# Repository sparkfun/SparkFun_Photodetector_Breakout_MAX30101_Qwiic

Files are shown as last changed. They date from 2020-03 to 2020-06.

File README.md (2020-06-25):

SparkFun Photodetector Breakout - MAX30101 (Qwiic)
========================================

SparkFun Photodetector Breakout - MAX30101) (https://www.sparkfun.com/products/16474)

[*SparkFun Photodetector Breakout - MAX30101 (Qwiic) (SEN-16474)*](https://www.sparkfun.com/products/16474)

This updated version of the [SparkFun Particle Sensor Breakout](https://www.sparkfun.com/products/14045) includes the MAX30101, a highly sensitive optical sensor and successor to the MAX30105 and MAX30102. The MAX30101 includes three LEDs and an optical detector in a single package. The operating principle behind the sensor, utilizes the photon detector to measure the amount of light that is reflected back from the light being emitted by the LEDs. This is useful for various applications like particle (*i.e. smoke*) detection, proximity measurements, and even [photoplethysmography](https://en.wikipedia.org/wiki/Photoplethysmogram). For more accurate and reliable biometric readings, we recommend the [SparkFun Pulse Oximeter and Heart Rate Sensor](https://www.sparkfun.com/products/15219), which utilizes proprietary algorithms programmed on the MAX32664 Biometric Sensor Hub.

<div class="alert alert-danger"><a href="https://www.sparkfun.com/terms"><b>&#9760; NOTE:</b> Our products are <b><u>NOT</u></b> intended to diagnose or treat any conditions and in life saving applications.</a></div>

Repository Contents
-------------------

* **/Documentation** - Data sheets, additional product information
* **/Hardware** - Eagle design files (.brd, .sch)
* **/Hardware/Production** - Production panel files and gerbers (.brd)

Documentation
--------------

* **[Hookup Guide](https://learn.sparkfun.com/tutorials/sparkfun-photodetector-max30101-hookup-guide)** - Basic hookup guide for the SparkFun Photodetector Breakout - MAX30101 (Qwiic).
* **[Python Package](https://github.com/sparkfun/Qwiic_MAX3010x_Py)** - Python package with examples. Pip and Pip3 install supported!!
* **[Arduino Library](https://github.com/sparkfun/SparkFun_MAX3010x_Sensor_Library)** - Basic Arduino Library for the SparkFun Photodetector Breakout - MAX30101 (Qwiic).

License Information
-------------------

This product is _**open source**_! 

Please review the LICENSE.md file for license information. 

If you have any questions or concerns on licensing, please contact technical support on our [SparkFun forums](https://forum.sparkfun.com/viewforum.php?f=152).

Distributed as-is; no warranty is given.

- Your friends at SparkFun.

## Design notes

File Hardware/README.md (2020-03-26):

SparkFun Particle Sensor MAX30101 (Qwiic) Design Files
=====================================

The .sch and .brd files hare are Eagle CAD schematic and PCB design files from SparkFun Electronics.
A freeware version of Eagle can be found [here](https://www.autodesk.com/products/eagle/free-download).

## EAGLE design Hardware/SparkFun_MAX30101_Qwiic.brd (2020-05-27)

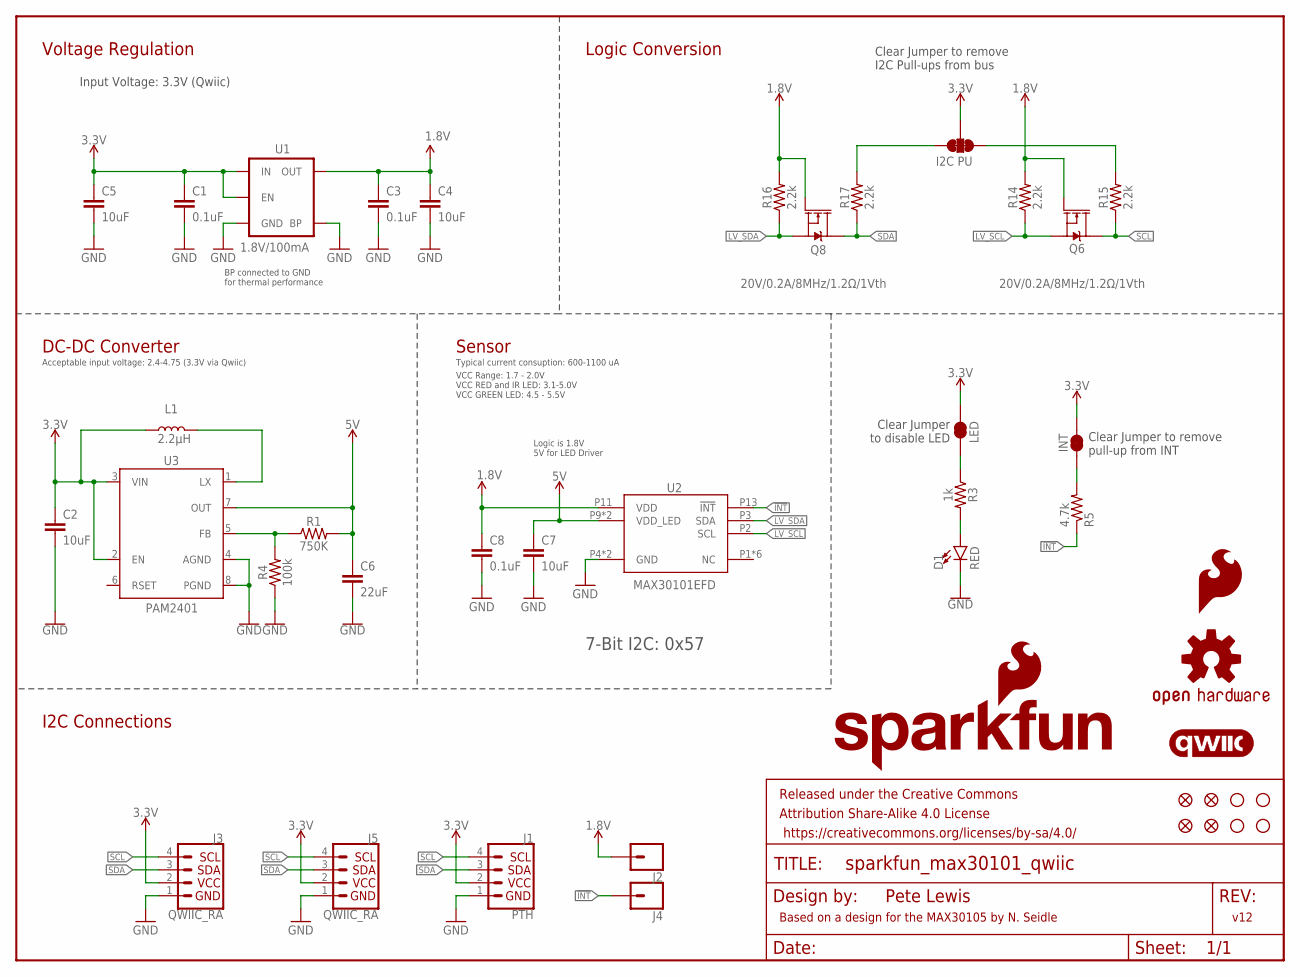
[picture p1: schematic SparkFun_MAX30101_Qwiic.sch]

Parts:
C1, C3, C8: 0.1uF; 0402
C2, C4, C5, C7: 10uF; 0603
C6: 22uF; 0805
D1: RED; LED-0603
FID1, FID2, FID3, FID4: FIDUCIAL1X2; FIDUCIAL-1X2
FRAME1: FRAME-LETTER; CREATIVE_COMMONS
J1: PTH; 1X04_NO_SILK
J2, J4: CONN_01PTH_NO_SILK_YES_STOP; 1X01_NO_SILK
J3, J5: QWIIC_RA; JST04_1MM_RA
JP1: LED; SMT-JUMPER_2_NC_TRACE_SILK
JP2: INT; SMT-JUMPER_2_NC_TRACE_SILK
JP4: I2C PU; SMT-JUMPER_3_2-NC_TRACE_SILK
L1: 2.2μH; 0806
LOGO1: SFE_LOGO_NAME_FLAME.1_INCH; SFE_LOGO_NAME_FLAME_.1
LOGO2: OSHW-LOGOS; OSHW-LOGO-S
LOGO3: QWIIC_LOGO_5MM; QWIIC_5MM
LOGO4: SFE_LOGO_FLAME.1_INCH; SFE_LOGO_FLAME_.1
Q6, Q8: 20V/0.2A/8MHz/1.2Ω/1Vth; SOT-416FL
R1: 750K; 0603
R3: 1k; 0603
R4: 100k; 0603
R5: 4.7k; 0603
R14, R15, R16, R17: 2.2k; 0603
STANDOFF1, STANDOFF2, STANDOFF3, STANDOFF4: STAND-OFF
U1: 1.8V/100mA; SC70
U2: MAX30101EFD; 14_PIN_OESIP
U3: PAM2401; MSOP8

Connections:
1.8V: C3.1, C4.1, C8.1, J2.1, Q6.1 (G), Q8.1 (G), R14.2, R16.2, U1.5 (OUT), U2.P11 (VDD)
3.3V: C1.1, C2.1, C5.1, J1.2, J3.2, J5.2, JP1.2, JP2.2, JP4.2, L1.1, U1.1 (IN), U1.3 (EN), U3.2 (EN), U3.3 (VIN)
5V: C6.1, C7.1, R1.2, U2.P9 (VDD_LED), U2.P10 (VDD_LED), U3.7 (OUT)
!INT: J4.1, R5.1, U2.P13 (!INT)
GND: C1.2, C2.2, C3.2, C4.2, C5.2, C6.2, C7.2, C8.2, D1.C, J1.1, J3.1, J5.1, R4.1, U1.2 (GND), U1.4 (BP), U2.P4 (GND), U2.P12 (GND), U3.4 (AGND), U3.8 (PGND)
LV_SCL: Q6.2 (S), R14.1, U2.P2 (SCL)
LV_SDA: Q8.2 (S), R16.1, U2.P3 (SDA)
unnamed: JP2.1, R5.2
unnamed: R1.1, R4.2, U3.5 (FB)
unnamed: L1.2, U3.1 (LX)
unnamed: D1.A, R3.2
unnamed: JP4.3, R15.2
unnamed: JP4.1, R17.2
unnamed: JP1.1, R3.1
SCL: J1.4, J3.4, J5.4, Q6.3 (D), R15.1
SDA: J1.3, J3.3, J5.3, Q8.3 (D), R17.1

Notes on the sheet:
7-Bit I2C: 0x57
v12
Pete Lewis
Voltage Regulation
Logic Conversion
Sensor
Input Voltage: 3.3V (Qwiic)
Clear Jumper to remove I2C Pull-ups from bus
Clear Jumper to remove pull-up from INT
Logic is 1.8V 5V for LED Driver
BP connected to GND for thermal performance
I2C Connections
Based on a design for the MAX30105 by N. Seidle
Clear Jumper to disable LED
DC-DC Converter
Typical current consuption: 600-1100 uA
VCC Range: 1.7 - 2.0V VCC RED and IR LED: 3.1-5.0V VCC GREEN LED: 4.5 - 5.5V
Acceptable input voltage: 2.4-4.75 (3.3V via Qwiic)

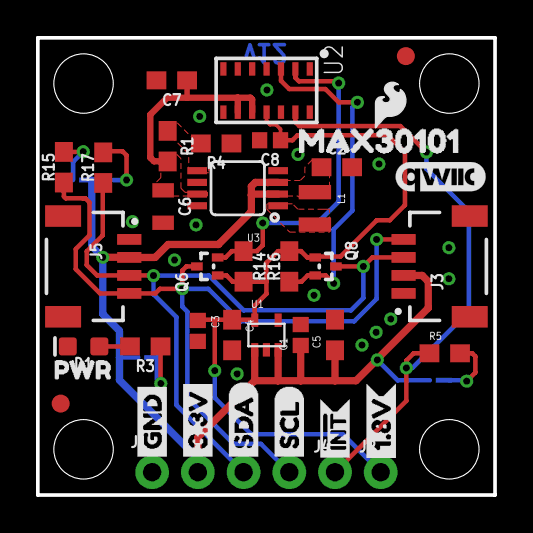
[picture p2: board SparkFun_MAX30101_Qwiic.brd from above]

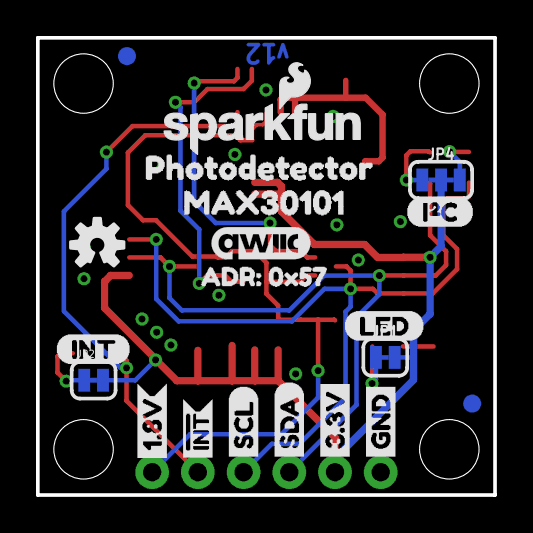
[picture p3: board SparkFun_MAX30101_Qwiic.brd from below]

Board: 2 copper layers, 25.4 x 25.4 mm, 65 parts (20 on the bottom side), 16 nets.

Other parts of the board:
U$1: PHOTODETECTOR3
U$3, U$11: INT#-[<-04
U$4, U$24: MAX301010
U$7: INT-()-04
U$8: LED0
U$9, U$12: SCL-[)
U$10, U$23: GND-04
U$13, U$14: SDA-[)
U$15: ADR#_0X570
U$16: QWIIC_5.5MM
U$19, U$22: 3.3V
U$20, U$27: 1#8V0
U$21: I_SUPER2_C-()-04
U$26: PWR_TO

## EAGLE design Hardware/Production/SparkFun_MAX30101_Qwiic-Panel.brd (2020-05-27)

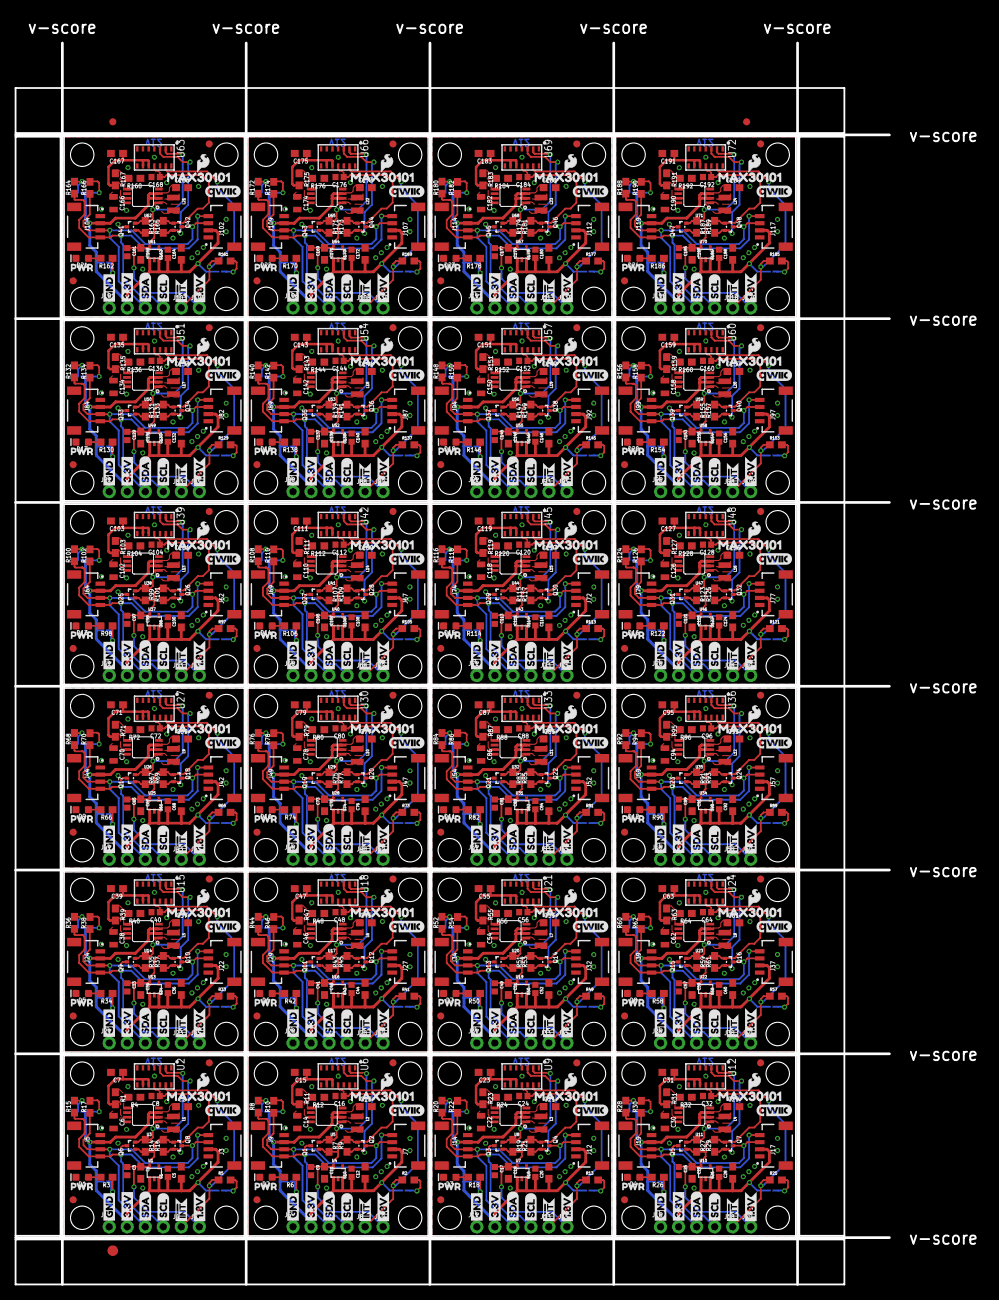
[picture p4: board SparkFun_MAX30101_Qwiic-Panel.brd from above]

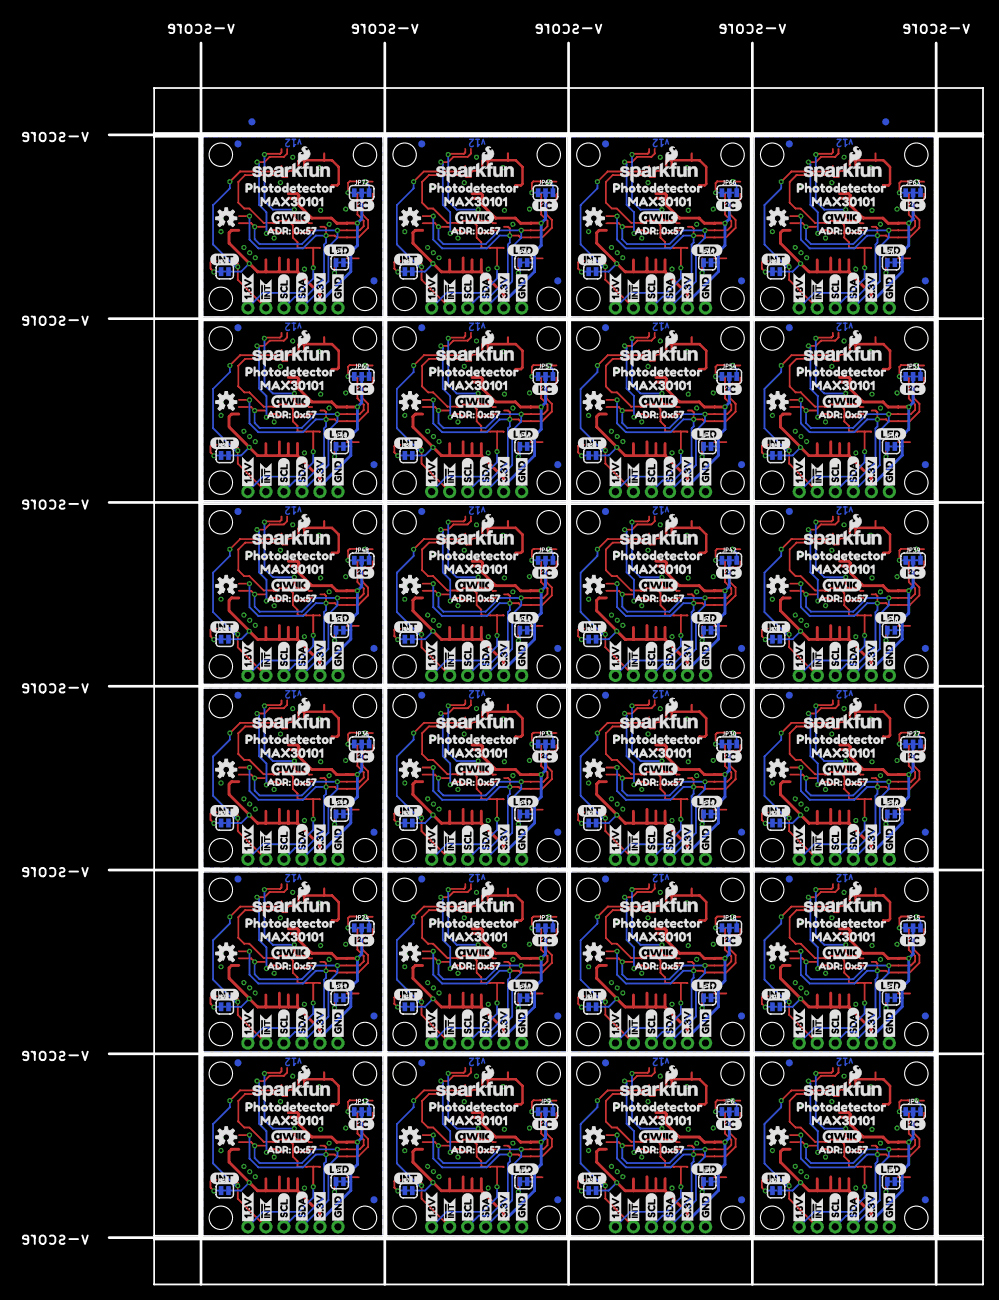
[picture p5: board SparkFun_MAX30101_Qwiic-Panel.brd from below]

Board: 2 copper layers, 123.2 x 175.0 mm, 1541 parts (482 on the bottom side), 384 nets.

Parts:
C1, C3, C8, C9, C10, C16, C17, C18, C24, C25, C26, C32, C33, C34, C40, C41, C42, C48, C49, C50, C56, C57, C58, C64, C65, C66, C72, C73, C74, C80, C81, C82, C88, C89, C90, C96, C97, C98, C104, C105, C106, C112, C113, C114, C120, C121, C122, C128, C129, C130, C136, C137, C138, C144, C145, C146, C152, C153, C154, C160, C161, C162, C168, C169, C170, C176, C177, C178, C184, C185, C186, C192: 0.1uF; 0402
C2, C4, C5, C7, C11, C12, C13, C15, C19, C20, C21, C23, C27, C28, C29, C31, C35, C36, C37, C39, C43, C44, C45, C47, C51, C52, C53, C55, C59, C60, C61, C63, C67, C68, C69, C71, C75, C76, C77, C79, C83, C84, C85, C87, C91, C92, C93, C95, C99, C100, C101, C103, C107, C108, C109, C111, C115, C116, C117, C119, C123, C124, C125, C127, C131, C132, C133, C135, C139, C140, C141, C143, C147, C148, C149, C151, C155, C156, C157, C159, C163, C164, C165, C167, C171, C172, C173, C175, C179, C180, C181, C183, C187, C188, C189, C191: 10uF; 0603
C6, C14, C22, C30, C38, C46, C54, C62, C70, C78, C86, C94, C102, C110, C118, C126, C134, C142, C150, C158, C166, C174, C182, C190: 22uF; 0805
D1, D2, D3, D4, D5, D6, D7, D8, D9, D10, D11, D12, D13, D14, D15, D16, D17, D18, D19, D20, D21, D22, D23, D24: RED; LED-0603
E$1, E$2, E$3, E$4: FIDUCIAL-1X2
E$5: FIDUCIAL-1.5X3
FID1, FID2, FID3, FID4, FID5, FID6, FID7, FID8, FID9, FID10, FID11, FID12, FID13, FID14, FID15, FID16, FID17, FID18, FID19, FID20, FID21, FID22, FID23, FID24, FID25, FID26, FID27, FID28, FID29, FID30, FID31, FID32, FID33, FID34, FID35, FID36, FID37, FID38, FID39, FID40, FID41, FID42, FID43, FID44, FID45, FID46, FID47, FID48, FID49, FID50, FID51, FID52, FID53, FID54, FID55, FID56, FID57, FID58, FID59, FID60, FID61, FID62, FID63, FID64, FID65, FID66, FID67, FID68, FID69, FID70, FID71, FID72, FID73, FID74, FID75, FID76, FID77, FID78, FID79, FID80, FID81, FID82, FID83, FID84, FID85, FID86, FID87, FID88, FID89, FID90, FID91, FID92, FID93, FID94, FID95, FID96: FIDUCIAL1X2; FIDUCIAL-1X2
J1, J6, J11, J16, J21, J26, J31, J36, J41, J46, J51, J56, J61, J66, J71, J76, J81, J86, J91, J96, J101, J106, J111, J116: PTH; 1X04_NO_SILK
J2, J4, J8, J10, J13, J15, J18, J20, J23, J25, J28, J30, J33, J35, J38, J40, J43, J45, J48, J50, J53, J55, J58, J60, J63, J65, J68, J70, J73, J75, J78, J80, J83, J85, J88, J90, J93, J95, J98, J100, J103, J105, J108, J110, J113, J115, J118, J120: 1X01_NO_SILK
J3, J5, J7, J9, J12, J14, J17, J19, J22, J24, J27, J29, J32, J34, J37, J39, J42, J44, J47, J49, J52, J54, J57, J59, J62, J64, J67, J69, J72, J74, J77, J79, J82, J84, J87, J89, J92, J94, J97, J99, J102, J104, J107, J109, J112, J114, J117, J119: QWIIC_RA; JST04_1MM_RA
JP1, JP5, JP8, JP11, JP14, JP17, JP20, JP23, JP26, JP29, JP32, JP35, JP38, JP41, JP44, JP47, JP50, JP53, JP56, JP59, JP62, JP65, JP68, JP71: LED; SMT-JUMPER_2_NC_TRACE_SILK
JP2, JP3, JP7, JP10, JP13, JP16, JP19, JP22, JP25, JP28, JP31, JP34, JP37, JP40, JP43, JP46, JP49, JP52, JP55, JP58, JP61, JP64, JP67, JP70: INT; SMT-JUMPER_2_NC_TRACE_SILK
JP4, JP6, JP9, JP12, JP15, JP18, JP21, JP24, JP27, JP30, JP33, JP36, JP39, JP42, JP45, JP48, JP51, JP54, JP57, JP60, JP63, JP66, JP69, JP72: I2C PU; SMT-JUMPER_3_2-NC_TRACE_SILK
L1, L2, L3, L4, L5, L6, L7, L8, L9, L10, L11, L12, L13, L14, L15, L16, L17, L18, L19, L20, L21, L22, L23, L24: 2.2μH; 0806
LOGO1, LOGO5, LOGO9, LOGO13, LOGO17, LOGO21, LOGO25, LOGO29, LOGO33, LOGO37, LOGO41, LOGO45, LOGO49, LOGO53, LOGO57, LOGO61, LOGO65, LOGO69, LOGO73, LOGO77, LOGO81, LOGO85, LOGO89, LOGO93: SFE_LOGO_NAME_FLAME.1_INCH; SFE_LOGO_NAME_FLAME_.1
LOGO2, LOGO6, LOGO10, LOGO14, LOGO18, LOGO22, LOGO26, LOGO30, LOGO34, LOGO38, LOGO42, LOGO46, LOGO50, LOGO54, LOGO58, LOGO62, LOGO66, LOGO70, LOGO74, LOGO78, LOGO82, LOGO86, LOGO90, LOGO94: OSHW-LOGOS; OSHW-LOGO-S
LOGO3, LOGO8, LOGO12, LOGO16, LOGO20, LOGO24, LOGO28, LOGO32, LOGO36, LOGO40, LOGO44, LOGO48, LOGO52, LOGO56, LOGO60, LOGO64, LOGO68, LOGO72, LOGO76, LOGO80, LOGO84, LOGO88, LOGO92, LOGO96: QWIIC_LOGO_5MM; QWIIC_5MM
LOGO4, LOGO7, LOGO11, LOGO15, LOGO19, LOGO23, LOGO27, LOGO31, LOGO35, LOGO39, LOGO43, LOGO47, LOGO51, LOGO55, LOGO59, LOGO63, LOGO67, LOGO71, LOGO75, LOGO79, LOGO83, LOGO87, LOGO91, LOGO95: SFE_LOGO_FLAME.1_INCH; SFE_LOGO_FLAME_.1
Q1, Q2, Q3, Q4, Q5, Q6, Q7, Q8, Q9, Q10, Q11, Q12, Q13, Q14, Q15, Q16, Q17, Q18, Q19, Q20, Q21, Q22, Q23, Q24, Q25, Q26, Q27, Q28, Q29, Q30, Q31, Q32, Q33, Q34, Q35, Q36, Q37, Q38, Q39, Q40, Q41, Q42, Q43, Q44, Q45, Q46, Q47, Q48: 20V/0.2A/8MHz/1.2Ω/1Vth; SOT-416FL
R1, R11, R23, R31, R39, R47, R55, R63, R71, R79, R87, R95, R103, R111, R119, R127, R135, R143, R151, R159, R167, R175, R183, R191: 750K; 0603
R2, R5, R13, R25, R33, R41, R49, R57, R65, R73, R81, R89, R97, R105, R113, R121, R129, R137, R145, R153, R161, R169, R177, R185: 4.7k; 0603
R3, R6, R18, R26, R34, R42, R50, R58, R66, R74, R82, R90, R98, R106, R114, R122, R130, R138, R146, R154, R162, R170, R178, R186: 1k; 0603
R4, R12, R24, R32, R40, R48, R56, R64, R72, R80, R88, R96, R104, R112, R120, R128, R136, R144, R152, R160, R168, R176, R184, R192: 100k; 0603
R7, R8, R9, R10, R14, R15, R16, R17, R19, R20, R21, R22, R27, R28, R29, R30, R35, R36, R37, R38, R43, R44, R45, R46, R51, R52, R53, R54, R59, R60, R61, R62, R67, R68, R69, R70, R75, R76, R77, R78, R83, R84, R85, R86, R91, R92, R93, R94, R99, R100, R101, R102, R107, R108, R109, R110, R115, R116, R117, R118, R123, R124, R125, R126, R131, R132, R133, R134, R139, R140, R141, R142, R147, R148, R149, R150, R155, R156, R157, R158, R163, R164, R165, R166, R171, R172, R173, R174, R179, R180, R181, R182, R187, R188, R189, R190: 2.2k; 0603
STANDOFF1, STANDOFF2, STANDOFF3, STANDOFF4, STANDOFF5, STANDOFF6, STANDOFF7, STANDOFF8, STANDOFF9, STANDOFF10, STANDOFF11, STANDOFF12, STANDOFF13, STANDOFF14, STANDOFF15, STANDOFF16, STANDOFF17, STANDOFF18, STANDOFF19, STANDOFF20, STANDOFF21, STANDOFF22, STANDOFF23, STANDOFF24, STANDOFF25, STANDOFF26, STANDOFF27, STANDOFF28, STANDOFF29, STANDOFF30, STANDOFF31, STANDOFF32, STANDOFF33, STANDOFF34, STANDOFF35, STANDOFF36, STANDOFF37, STANDOFF38, STANDOFF39, STANDOFF40, STANDOFF41, STANDOFF42, STANDOFF43, STANDOFF44, STANDOFF45, STANDOFF46, STANDOFF47, STANDOFF48, STANDOFF49, STANDOFF50, STANDOFF51, STANDOFF52, STANDOFF53, STANDOFF54, STANDOFF55, STANDOFF56, STANDOFF57, STANDOFF58, STANDOFF59, STANDOFF60, STANDOFF61, STANDOFF62, STANDOFF63, STANDOFF64, STANDOFF65, STANDOFF66, STANDOFF67, STANDOFF68, STANDOFF69, STANDOFF70, STANDOFF71, STANDOFF72, STANDOFF73, STANDOFF74, STANDOFF75, STANDOFF76, STANDOFF77, STANDOFF78, STANDOFF79, STANDOFF80, STANDOFF81, STANDOFF82, STANDOFF83, STANDOFF84, STANDOFF85, STANDOFF86, STANDOFF87, STANDOFF88, STANDOFF89, STANDOFF90, STANDOFF91, STANDOFF92, STANDOFF93, STANDOFF94, STANDOFF95, STANDOFF96: STAND-OFF
U1, U4, U7, U10, U13, U16, U19, U22, U25, U28, U31, U34, U37, U40, U43, U46, U49, U52, U55, U58, U61, U64, U67, U70: 1.8V/100mA; SC70
U2, U6, U9, U12, U15, U18, U21, U24, U27, U30, U33, U36, U39, U42, U45, U48, U51, U54, U57, U60, U63, U66, U69, U72: MAX30101EFD; 14_PIN_OESIP
U3, U5, U8, U11, U14, U17, U20, U23, U26, U29, U32, U35, U38, U41, U44, U47, U50, U53, U56, U59, U62, U65, U68, U71: PAM2401; MSOP8
U$1, U$42, U$63, U$84, U$105, U$126, U$147, U$168, U$189, U$210, U$231, U$252, U$273, U$294, U$315, U$336, U$357, U$378, U$399, U$420, U$441, U$462, U$483, U$504: PHOTODETECTOR3
U$2, U$3, U$6, U$11, U$43, U$45, U$64, U$66, U$85, U$87, U$106, U$108, U$127, U$129, U$148, U$150, U$169, U$171, U$190, U$192, U$211, U$213, U$232, U$234, U$253, U$255, U$274, U$276, U$295, U$297, U$316, U$318, U$337, U$339, U$358, U$360, U$379, U$381, U$400, U$402, U$421, U$423, U$442, U$444, U$463, U$465, U$484, U$486: INT#-[<-04
U$4, U$24, U$35, U$37, U$56, U$58, U$77, U$79, U$98, U$100, U$119, U$121, U$140, U$142, U$161, U$163, U$182, U$184, U$203, U$205, U$224, U$226, U$245, U$247, U$266, U$268, U$287, U$289, U$308, U$310, U$329, U$331, U$350, U$352, U$371, U$373, U$392, U$394, U$413, U$415, U$434, U$436, U$455, U$457, U$476, U$478, U$497, U$499: MAX301010
U$5, U$9, U$12, U$29, U$44, U$50, U$65, U$71, U$86, U$92, U$107, U$113, U$128, U$134, U$149, U$155, U$170, U$176, U$191, U$197, U$212, U$218, U$233, U$239, U$254, U$260, U$275, U$281, U$296, U$302, U$317, U$323, U$338, U$344, U$359, U$365, U$380, U$386, U$401, U$407, U$422, U$428, U$443, U$449, U$464, U$470, U$485, U$491: SCL-[)
U$7, U$32, U$53, U$74, U$95, U$116, U$137, U$158, U$179, U$200, U$221, U$242, U$263, U$284, U$305, U$326, U$347, U$368, U$389, U$410, U$431, U$452, U$473, U$494: INT-()-04
U$8, U$34, U$55, U$76, U$97, U$118, U$139, U$160, U$181, U$202, U$223, U$244, U$265, U$286, U$307, U$328, U$349, U$370, U$391, U$412, U$433, U$454, U$475, U$496: LED0
U$10, U$23, U$25, U$28, U$48, U$49, U$69, U$70, U$90, U$91, U$111, U$112, U$132, U$133, U$153, U$154, U$174, U$175, U$195, U$196, U$216, U$217, U$237, U$238, U$258, U$259, U$279, U$280, U$300, U$301, U$321, U$322, U$342, U$343, U$363, U$364, U$384, U$385, U$405, U$406, U$426, U$427, U$447, U$448, U$468, U$469, U$489, U$490: GND-04
U$13, U$14, U$30, U$31, U$51, U$52, U$72, U$73, U$93, U$94, U$114, U$115, U$135, U$136, U$156, U$157, U$177, U$178, U$198, U$199, U$219, U$220, U$240, U$241, U$261, U$262, U$282, U$283, U$303, U$304, U$324, U$325, U$345, U$346, U$366, U$367, U$387, U$388, U$408, U$409, U$429, U$430, U$450, U$451, U$471, U$472, U$492, U$493: SDA-[)
U$15, U$38, U$59, U$80, U$101, U$122, U$143, U$164, U$185, U$206, U$227, U$248, U$269, U$290, U$311, U$332, U$353, U$374, U$395, U$416, U$437, U$458, U$479, U$500: ADR#_0X570
U$16, U$36, U$57, U$78, U$99, U$120, U$141, U$162, U$183, U$204, U$225, U$246, U$267, U$288, U$309, U$330, U$351, U$372, U$393, U$414, U$435, U$456, U$477, U$498: QWIIC_5.5MM
U$17, U$18, U$19, U$22, U$46, U$47, U$67, U$68, U$88, U$89, U$109, U$110, U$130, U$131, U$151, U$152, U$172, U$173, U$193, U$194, U$214, U$215, U$235, U$236, U$256, U$257, U$277, U$278, U$298, U$299, U$319, U$320, U$340, U$341, U$361, U$362, U$382, U$383, U$403, U$404, U$424, U$425, U$445, U$446, U$466, U$467, U$487, U$488: 3.3V
U$20, U$27, U$40, U$41, U$61, U$62, U$82, U$83, U$103, U$104, U$124, U$125, U$145, U$146, U$166, U$167, U$187, U$188, U$208, U$209, U$229, U$230, U$250, U$251, U$271, U$272, U$292, U$293, U$313, U$314, U$334, U$335, U$355, U$356, U$376, U$377, U$397, U$398, U$418, U$419, U$439, U$440, U$460, U$461, U$481, U$482, U$502, U$503: 1#8V0
U$21, U$33, U$54, U$75, U$96, U$117, U$138, U$159, U$180, U$201, U$222, U$243, U$264, U$285, U$306, U$327, U$348, U$369, U$390, U$411, U$432, U$453, U$474, U$495: I_SUPER2_C-()-04
U$26, U$39, U$60, U$81, U$102, U$123, U$144, U$165, U$186, U$207, U$228, U$249, U$270, U$291, U$312, U$333, U$354, U$375, U$396, U$417, U$438, U$459, U$480, U$501: PWR_TO

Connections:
1.8V: C3.1, C4.1, C8.1, J2.1, Q6.1, Q8.1, R14.2, R16.2, U1.5, U2.P11
1.8V1: C9.1, C11.1, C16.1, J10.1, Q1.1, Q2.1, R7.2, R9.2, U4.5, U6.P11
1.8V2: C17.1, C19.1, C24.1, J15.1, Q3.1, Q4.1, R19.2, R21.2, U7.5, U9.P11
1.8V3: C25.1, C27.1, C32.1, J20.1, Q5.1, Q7.1, R27.2, R29.2, U10.5, U12.P11
1.8V4: C33.1, C35.1, C40.1, J25.1, Q9.1, Q10.1, R35.2, R37.2, U13.5, U15.P11
1.8V5: C41.1, C43.1, C48.1, J30.1, Q11.1, Q12.1, R43.2, R45.2, U16.5, U18.P11
1.8V6: C49.1, C51.1, C56.1, J35.1, Q13.1, Q14.1, R51.2, R53.2, U19.5, U21.P11
1.8V7: C57.1, C59.1, C64.1, J40.1, Q15.1, Q16.1, R59.2, R61.2, U22.5, U24.P11
1.8V8: C65.1, C67.1, C72.1, J45.1, Q17.1, Q18.1, R67.2, R69.2, U25.5, U27.P11
1.8V9: C73.1, C75.1, C80.1, J50.1, Q19.1, Q20.1, R75.2, R77.2, U28.5, U30.P11
1.8V10: C81.1, C83.1, C88.1, J55.1, Q21.1, Q22.1, R83.2, R85.2, U31.5, U33.P11
1.8V11: C89.1, C91.1, C96.1, J60.1, Q23.1, Q24.1, R91.2, R93.2, U34.5, U36.P11
1.8V12: C97.1, C99.1, C104.1, J65.1, Q25.1, Q26.1, R99.2, R101.2, U37.5, U39.P11
1.8V13: C105.1, C107.1, C112.1, J70.1, Q27.1, Q28.1, R107.2, R109.2, U40.5, U42.P11
1.8V14: C113.1, C115.1, C120.1, J75.1, Q29.1, Q30.1, R115.2, R117.2, U43.5, U45.P11
1.8V15: C121.1, C123.1, C128.1, J80.1, Q31.1, Q32.1, R123.2, R125.2, U46.5, U48.P11
1.8V16: C129.1, C131.1, C136.1, J85.1, Q33.1, Q34.1, R131.2, R133.2, U49.5, U51.P11
1.8V17: C137.1, C139.1, C144.1, J90.1, Q35.1, Q36.1, R139.2, R141.2, U52.5, U54.P11
1.8V18: C145.1, C147.1, C152.1, J95.1, Q37.1, Q38.1, R147.2, R149.2, U55.5, U57.P11
1.8V19: C153.1, C155.1, C160.1, J100.1, Q39.1, Q40.1, R155.2, R157.2, U58.5, U60.P11
1.8V20: C161.1, C163.1, C168.1, J105.1, Q41.1, Q42.1, R163.2, R165.2, U61.5, U63.P11
1.8V21: C169.1, C171.1, C176.1, J110.1, Q43.1, Q44.1, R171.2, R173.2, U64.5, U66.P11
1.8V22: C177.1, C179.1, C184.1, J115.1, Q45.1, Q46.1, R179.2, R181.2, U67.5, U69.P11
1.8V23: C185.1, C187.1, C192.1, J120.1, Q47.1, Q48.1, R187.2, R189.2, U70.5, U72.P11
3.3V: C1.1, C2.1, C5.1, J1.2, J3.2, J5.2, JP1.2, JP2.2, JP4.2, L1.1, U1.1, U1.3, U3.2, U3.3
3.3V1: C10.1, C12.1, C13.1, J6.2, J7.2, J9.2, JP3.2, JP5.2, JP6.2, L2.1, U4.1, U4.3, U5.2, U5.3
3.3V2: C18.1, C20.1, C21.1, J11.2, J12.2, J14.2, JP7.2, JP8.2, JP9.2, L3.1, U7.1, U7.3, U8.2, U8.3
3.3V3: C26.1, C28.1, C29.1, J16.2, J17.2, J19.2, JP10.2, JP11.2, JP12.2, L4.1, U10.1, U10.3, U11.2, U11.3
3.3V4: C34.1, C36.1, C37.1, J21.2, J22.2, J24.2, JP13.2, JP14.2, JP15.2, L5.1, U13.1, U13.3, U14.2, U14.3
3.3V5: C42.1, C44.1, C45.1, J26.2, J27.2, J29.2, JP16.2, JP17.2, JP18.2, L6.1, U16.1, U16.3, U17.2, U17.3
3.3V6: C50.1, C52.1, C53.1, J31.2, J32.2, J34.2, JP19.2, JP20.2, JP21.2, L7.1, U19.1, U19.3, U20.2, U20.3
3.3V7: C58.1, C60.1, C61.1, J36.2, J37.2, J39.2, JP22.2, JP23.2, JP24.2, L8.1, U22.1, U22.3, U23.2, U23.3
3.3V8: C66.1, C68.1, C69.1, J41.2, J42.2, J44.2, JP25.2, JP26.2, JP27.2, L9.1, U25.1, U25.3, U26.2, U26.3
3.3V9: C74.1, C76.1, C77.1, J46.2, J47.2, J49.2, JP28.2, JP29.2, JP30.2, L10.1, U28.1, U28.3, U29.2, U29.3
3.3V10: C82.1, C84.1, C85.1, J51.2, J52.2, J54.2, JP31.2, JP32.2, JP33.2, L11.1, U31.1, U31.3, U32.2, U32.3
3.3V11: C90.1, C92.1, C93.1, J56.2, J57.2, J59.2, JP34.2, JP35.2, JP36.2, L12.1, U34.1, U34.3, U35.2, U35.3
3.3V12: C98.1, C100.1, C101.1, J61.2, J62.2, J64.2, JP37.2, JP38.2, JP39.2, L13.1, U37.1, U37.3, U38.2, U38.3
3.3V13: C106.1, C108.1, C109.1, J66.2, J67.2, J69.2, JP40.2, JP41.2, JP42.2, L14.1, U40.1, U40.3, U41.2, U41.3
3.3V14: C114.1, C116.1, C117.1, J71.2, J72.2, J74.2, JP43.2, JP44.2, JP45.2, L15.1, U43.1, U43.3, U44.2, U44.3
3.3V15: C122.1, C124.1, C125.1, J76.2, J77.2, J79.2, JP46.2, JP47.2, JP48.2, L16.1, U46.1, U46.3, U47.2, U47.3
3.3V16: C130.1, C132.1, C133.1, J81.2, J82.2, J84.2, JP49.2, JP50.2, JP51.2, L17.1, U49.1, U49.3, U50.2, U50.3
3.3V17: C138.1, C140.1, C141.1, J86.2, J87.2, J89.2, JP52.2, JP53.2, JP54.2, L18.1, U52.1, U52.3, U53.2, U53.3
3.3V18: C146.1, C148.1, C149.1, J91.2, J92.2, J94.2, JP55.2, JP56.2, JP57.2, L19.1, U55.1, U55.3, U56.2, U56.3
3.3V19: C154.1, C156.1, C157.1, J96.2, J97.2, J99.2, JP58.2, JP59.2, JP60.2, L20.1, U58.1, U58.3, U59.2, U59.3
3.3V20: C162.1, C164.1, C165.1, J101.2, J102.2, J104.2, JP61.2, JP62.2, JP63.2, L21.1, U61.1, U61.3, U62.2, U62.3
3.3V21: C170.1, C172.1, C173.1, J106.2, J107.2, J109.2, JP64.2, JP65.2, JP66.2, L22.1, U64.1, U64.3, U65.2, U65.3
3.3V22: C178.1, C180.1, C181.1, J111.2, J112.2, J114.2, JP67.2, JP68.2, JP69.2, L23.1, U67.1, U67.3, U68.2, U68.3
3.3V23: C186.1, C188.1, C189.1, J116.2, J117.2, J119.2, JP70.2, JP71.2, JP72.2, L24.1, U70.1, U70.3, U71.2, U71.3
5V: C6.1, C7.1, R1.2, U2.P9, U2.P10, U3.7
5V1: C14.1, C15.1, R11.2, U5.7, U6.P9, U6.P10
5V2: C22.1, C23.1, R23.2, U8.7, U9.P9, U9.P10
5V3: C30.1, C31.1, R31.2, U11.7, U12.P9, U12.P10
5V4: C38.1, C39.1, R39.2, U14.7, U15.P9, U15.P10
5V5: C46.1, C47.1, R47.2, U17.7, U18.P9, U18.P10
5V6: C54.1, C55.1, R55.2, U20.7, U21.P9, U21.P10
5V7: C62.1, C63.1, R63.2, U23.7, U24.P9, U24.P10
5V8: C70.1, C71.1, R71.2, U26.7, U27.P9, U27.P10
5V9: C78.1, C79.1, R79.2, U29.7, U30.P9, U30.P10
5V10: C86.1, C87.1, R87.2, U32.7, U33.P9, U33.P10
5V11: C94.1, C95.1, R95.2, U35.7, U36.P9, U36.P10
5V12: C102.1, C103.1, R103.2, U38.7, U39.P9, U39.P10
5V13: C110.1, C111.1, R111.2, U41.7, U42.P9, U42.P10
5V14: C118.1, C119.1, R119.2, U44.7, U45.P9, U45.P10
5V15: C126.1, C127.1, R127.2, U47.7, U48.P9, U48.P10
5V16: C134.1, C135.1, R135.2, U50.7, U51.P9, U51.P10
5V17: C142.1, C143.1, R143.2, U53.7, U54.P9, U54.P10
5V18: C150.1, C151.1, R151.2, U56.7, U57.P9, U57.P10
5V19: C158.1, C159.1, R159.2, U59.7, U60.P9, U60.P10
5V20: C166.1, C167.1, R167.2, U62.7, U63.P9, U63.P10
5V21: C174.1, C175.1, R175.2, U65.7, U66.P9, U66.P10
5V22: C182.1, C183.1, R183.2, U68.7, U69.P9, U69.P10
5V23: C190.1, C191.1, R191.2, U71.7, U72.P9, U72.P10
!INT: J4.1, R5.1, U2.P13
!INT1: J8.1, R2.1, U6.P13
!INT2: J13.1, R13.1, U9.P13
!INT3: J18.1, R25.1, U12.P13
!INT4: J23.1, R33.1, U15.P13
!INT5: J28.1, R41.1, U18.P13
!INT6: J33.1, R49.1, U21.P13
!INT7: J38.1, R57.1, U24.P13
!INT8: J43.1, R65.1, U27.P13
!INT9: J48.1, R73.1, U30.P13
!INT10: J53.1, R81.1, U33.P13
!INT11: J58.1, R89.1, U36.P13
!INT12: J63.1, R97.1, U39.P13
!INT13: J68.1, R105.1, U42.P13
!INT14: J73.1, R113.1, U45.P13
!INT15: J78.1, R121.1, U48.P13
!INT16: J83.1, R129.1, U51.P13
!INT17: J88.1, R137.1, U54.P13
!INT18: J93.1, R145.1, U57.P13
!INT19: J98.1, R153.1, U60.P13
!INT20: J103.1, R161.1, U63.P13
!INT21: J108.1, R169.1, U66.P13
!INT22: J113.1, R177.1, U69.P13
!INT23: J118.1, R185.1, U72.P13
GND: C1.2, C2.2, C3.2, C4.2, C5.2, C6.2, C7.2, C8.2, D1.C, J1.1, J3.1, J5.1, R4.1, U1.2, U1.4, U2.P4, U2.P12, U3.4, U3.8
GND1: C9.2, C10.2, C11.2, C12.2, C13.2, C14.2, C15.2, C16.2, D2.C, J6.1, J7.1, J9.1, R12.1, U4.2, U4.4, U5.4, U5.8, U6.P4, U6.P12
GND2: C17.2, C18.2, C19.2, C20.2, C21.2, C22.2, C23.2, C24.2, D3.C, J11.1, J12.1, J14.1, R24.1, U7.2, U7.4, U8.4, U8.8, U9.P4, U9.P12
GND3: C25.2, C26.2, C27.2, C28.2, C29.2, C30.2, C31.2, C32.2, D4.C, J16.1, J17.1, J19.1, R32.1, U10.2, U10.4, U11.4, U11.8, U12.P4, U12.P12
GND4: C33.2, C34.2, C35.2, C36.2, C37.2, C38.2, C39.2, C40.2, D5.C, J21.1, J22.1, J24.1, R40.1, U13.2, U13.4, U14.4, U14.8, U15.P4, U15.P12
GND5: C41.2, C42.2, C43.2, C44.2, C45.2, C46.2, C47.2, C48.2, D6.C, J26.1, J27.1, J29.1, R48.1, U16.2, U16.4, U17.4, U17.8, U18.P4, U18.P12
GND6: C49.2, C50.2, C51.2, C52.2, C53.2, C54.2, C55.2, C56.2, D7.C, J31.1, J32.1, J34.1, R56.1, U19.2, U19.4, U20.4, U20.8, U21.P4, U21.P12
GND7: C57.2, C58.2, C59.2, C60.2, C61.2, C62.2, C63.2, C64.2, D8.C, J36.1, J37.1, J39.1, R64.1, U22.2, U22.4, U23.4, U23.8, U24.P4, U24.P12
GND8: C65.2, C66.2, C67.2, C68.2, C69.2, C70.2, C71.2, C72.2, D9.C, J41.1, J42.1, J44.1, R72.1, U25.2, U25.4, U26.4, U26.8, U27.P4, U27.P12
GND9: C73.2, C74.2, C75.2, C76.2, C77.2, C78.2, C79.2, C80.2, D10.C, J46.1, J47.1, J49.1, R80.1, U28.2, U28.4, U29.4, U29.8, U30.P4, U30.P12
GND10: C81.2, C82.2, C83.2, C84.2, C85.2, C86.2, C87.2, C88.2, D11.C, J51.1, J52.1, J54.1, R88.1, U31.2, U31.4, U32.4, U32.8, U33.P4, U33.P12
GND11: C89.2, C90.2, C91.2, C92.2, C93.2, C94.2, C95.2, C96.2, D12.C, J56.1, J57.1, J59.1, R96.1, U34.2, U34.4, U35.4, U35.8, U36.P4, U36.P12
GND12: C97.2, C98.2, C99.2, C100.2, C101.2, C102.2, C103.2, C104.2, D13.C, J61.1, J62.1, J64.1, R104.1, U37.2, U37.4, U38.4, U38.8, U39.P4, U39.P12
GND13: C105.2, C106.2, C107.2, C108.2, C109.2, C110.2, C111.2, C112.2, D14.C, J66.1, J67.1, J69.1, R112.1, U40.2, U40.4, U41.4, U41.8, U42.P4, U42.P12
GND14: C113.2, C114.2, C115.2, C116.2, C117.2, C118.2, C119.2, C120.2, D15.C, J71.1, J72.1, J74.1, R120.1, U43.2, U43.4, U44.4, U44.8, U45.P4, U45.P12
GND15: C121.2, C122.2, C123.2, C124.2, C125.2, C126.2, C127.2, C128.2, D16.C, J76.1, J77.1, J79.1, R128.1, U46.2, U46.4, U47.4, U47.8, U48.P4, U48.P12
GND16: C129.2, C130.2, C131.2, C132.2, C133.2, C134.2, C135.2, C136.2, D17.C, J81.1, J82.1, J84.1, R136.1, U49.2, U49.4, U50.4, U50.8, U51.P4, U51.P12
GND17: C137.2, C138.2, C139.2, C140.2, C141.2, C142.2, C143.2, C144.2, D18.C, J86.1, J87.1, J89.1, R144.1, U52.2, U52.4, U53.4, U53.8, U54.P4, U54.P12
GND18: C145.2, C146.2, C147.2, C148.2, C149.2, C150.2, C151.2, C152.2, D19.C, J91.1, J92.1, J94.1, R152.1, U55.2, U55.4, U56.4, U56.8, U57.P4, U57.P12
GND19: C153.2, C154.2, C155.2, C156.2, C157.2, C158.2, C159.2, C160.2, D20.C, J96.1, J97.1, J99.1, R160.1, U58.2, U58.4, U59.4, U59.8, U60.P4, U60.P12
GND20: C161.2, C162.2, C163.2, C164.2, C165.2, C166.2, C167.2, C168.2, D21.C, J101.1, J102.1, J104.1, R168.1, U61.2, U61.4, U62.4, U62.8, U63.P4, U63.P12
GND21: C169.2, C170.2, C171.2, C172.2, C173.2, C174.2, C175.2, C176.2, D22.C, J106.1, J107.1, J109.1, R176.1, U64.2, U64.4, U65.4, U65.8, U66.P4, U66.P12
GND22: C177.2, C178.2, C179.2, C180.2, C181.2, C182.2, C183.2, C184.2, D23.C, J111.1, J112.1, J114.1, R184.1, U67.2, U67.4, U68.4, U68.8, U69.P4, U69.P12
GND23: C185.2, C186.2, C187.2, C188.2, C189.2, C190.2, C191.2, C192.2, D24.C, J116.1, J117.1, J119.1, R192.1, U70.2, U70.4, U71.4, U71.8, U72.P4, U72.P12
LV_SCL: Q6.2, R14.1, U2.P2
LV_SCL1: Q1.2, R7.1, U6.P2
LV_SCL2: Q3.2, R19.1, U9.P2
LV_SCL3: Q5.2, R27.1, U12.P2
LV_SCL4: Q9.2, R35.1, U15.P2
LV_SCL5: Q11.2, R43.1, U18.P2
LV_SCL6: Q13.2, R51.1, U21.P2
LV_SCL7: Q15.2, R59.1, U24.P2
LV_SCL8: Q17.2, R67.1, U27.P2
LV_SCL9: Q19.2, R75.1, U30.P2
LV_SCL10: Q21.2, R83.1, U33.P2
LV_SCL11: Q23.2, R91.1, U36.P2
LV_SCL12: Q25.2, R99.1, U39.P2
LV_SCL13: Q27.2, R107.1, U42.P2
LV_SCL14: Q29.2, R115.1, U45.P2
LV_SCL15: Q31.2, R123.1, U48.P2
LV_SCL16: Q33.2, R131.1, U51.P2
LV_SCL17: Q35.2, R139.1, U54.P2
LV_SCL18: Q37.2, R147.1, U57.P2
LV_SCL19: Q39.2, R155.1, U60.P2
LV_SCL20: Q41.2, R163.1, U63.P2
LV_SCL21: Q43.2, R171.1, U66.P2
LV_SCL22: Q45.2, R179.1, U69.P2
LV_SCL23: Q47.2, R187.1, U72.P2
LV_SDA: Q8.2, R16.1, U2.P3
LV_SDA1: Q2.2, R9.1, U6.P3
LV_SDA2: Q4.2, R21.1, U9.P3
LV_SDA3: Q7.2, R29.1, U12.P3
LV_SDA4: Q10.2, R37.1, U15.P3
LV_SDA5: Q12.2, R45.1, U18.P3
LV_SDA6: Q14.2, R53.1, U21.P3
LV_SDA7: Q16.2, R61.1, U24.P3
LV_SDA8: Q18.2, R69.1, U27.P3
LV_SDA9: Q20.2, R77.1, U30.P3
LV_SDA10: Q22.2, R85.1, U33.P3
LV_SDA11: Q24.2, R93.1, U36.P3
LV_SDA12: Q26.2, R101.1, U39.P3
LV_SDA13: Q28.2, R109.1, U42.P3
LV_SDA14: Q30.2, R117.1, U45.P3
LV_SDA15: Q32.2, R125.1, U48.P3
LV_SDA16: Q34.2, R133.1, U51.P3
LV_SDA17: Q36.2, R141.1, U54.P3
LV_SDA18: Q38.2, R149.1, U57.P3
LV_SDA19: Q40.2, R157.1, U60.P3
LV_SDA20: Q42.2, R165.1, U63.P3
LV_SDA21: Q44.2, R173.1, U66.P3
LV_SDA22: Q46.2, R181.1, U69.P3
LV_SDA23: Q48.2, R189.1, U72.P3
unnamed: JP2.1, R5.2
unnamed: R1.1, R4.2, U3.5
unnamed: L1.2, U3.1
unnamed: D1.A, R3.2
unnamed: JP4.3, R15.2
unnamed: JP4.1, R17.2
unnamed: JP3.1, R2.2
unnamed: JP1.1, R3.1
unnamed: D2.A, R6.2
unnamed: JP5.1, R6.1
unnamed: JP6.3, R8.2
unnamed: JP6.1, R10.2
unnamed: R11.1, R12.2, U5.5
unnamed: L2.2, U5.1
unnamed: JP7.1, R13.2
unnamed: D3.A, R18.2
unnamed: JP8.1, R18.1
unnamed: JP9.3, R20.2
unnamed: JP9.1, R22.2
unnamed: R23.1, R24.2, U8.5
unnamed: L3.2, U8.1
unnamed: JP10.1, R25.2
unnamed: D4.A, R26.2
unnamed: JP11.1, R26.1
unnamed: JP12.3, R28.2
unnamed: JP12.1, R30.2
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

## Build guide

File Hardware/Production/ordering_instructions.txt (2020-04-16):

panel size, 117x162mm
PCB thickness, 1.6mm
number of layers, 2
soldermask color, Red
silkscreen color, White
oz copper, 1oz
finish, HASL lead free
stencils, top+bottom
pcs per panel, 24
min trace width, 0.2032mm / 0.0080in
min drill size, 0.3810mm / 0.0150in

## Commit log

2020-03-26 v10 hardware design files
    [SparkFun_MAX30101_Qwiic.brd, SparkFun_MAX30101_Qwiic.sch]
2020-03-27 Qwiic logo in SCH and sch cleanup
    [SparkFun_MAX30101_Qwiic.brd, SparkFun_MAX30101_Qwiic.sch]
2020-03-27 Added I2C address to bottom silk
    [SparkFun_MAX30101_Qwiic.brd]
2020-04-10 Added 5V step up for green LED and review changes
    -Added in 5V step up circuit to provide 5V for Green LED
    -Add fids to bottom
    -move power led label to text only
    -3.3V trace could loose a via and then stitch up gnd with more vias
    -move IC device to the true MAX30105 in the library.
    -flip v10 in copper to read "along" the bottom.
    -remove JP labels to jumpers, since they already have the names of their purposes.
    -input voltage range in sch.
    -Change 1.8V label flag to an output
    -add typical current consuption for the sensor in the schematic near the IC symbol
    -Move QWIIC lozenge to right over by the qwiic connector.
    [SparkFun_MAX30101_Qwiic.brd, SparkFun_MAX30101_Qwiic.sch]
2020-04-10 design review #2 changes (post DC-DC converter addition)
    -cleaned up sch around DC-DC converter
    -added silk outline to MAX30101 IC
    -replaced 4.7K resistor to updated package (without silk under it)
    -updated Mosfets on logic level translation to latest library devices
    [SparkFun_MAX30101_Qwiic.brd, SparkFun_MAX30101_Qwiic.sch]
2020-04-16 Added more bypass caps to 5V and 1.8V, bumped version to v11
    [SparkFun_MAX30101_Qwiic.brd, SparkFun_MAX30101_Qwiic.sch]
2020-04-16 Production panel file and gerbers
    [SparkFun_MAX30101_Qwiic-Panel.GBL, SparkFun_MAX30101_Qwiic-Panel.GBO, SparkFun_MAX30101_Qwiic-Panel.GBP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]
2020-05-27 Updated name silk to "Photodetector"
    Also bumped version to v12 on sch and brd
    [SparkFun_MAX30101_Qwiic.brd, SparkFun_MAX30101_Qwiic.sch]
2020-05-27 Production panel updated to v12
    [SparkFun_MAX30101_Qwiic-Panel.brd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]

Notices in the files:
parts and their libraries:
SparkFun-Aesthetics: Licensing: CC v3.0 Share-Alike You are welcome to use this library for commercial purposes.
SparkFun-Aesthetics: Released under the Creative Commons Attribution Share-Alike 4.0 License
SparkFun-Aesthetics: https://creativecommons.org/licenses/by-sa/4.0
